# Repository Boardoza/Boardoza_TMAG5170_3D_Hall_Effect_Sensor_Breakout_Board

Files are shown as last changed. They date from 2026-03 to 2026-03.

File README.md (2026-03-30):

# Boardoza TMAG5170 3D Hall-Effect Sensor Breakout Board

The **Boardoza TMAG5170** is a high-precision **3D linear hall-effect sensor breakout board** based on the **Texas Instruments TMAG5170**. This device integrates **three independent Hall sensors (X, Y, and Z axes)** along with a precision signal chain and a 12-bit ADC, enabling accurate magnetic field measurement in compact and high-performance systems.

With support for high-speed **SPI communication (up to 10 MHz)** and sampling rates up to **20 ksps**, the TMAG5170 is ideal for real-time direction sensing applications. Integrated diagnostics, angle calculation (CORDIC engine), and an on-chip temperature sensor provide enhanced reliability and system-level drift compensation. This breakout board is perfect for **industrial automation, robotics, motor control, contactless direction sensing, and smart mechatronic systems.**

## [Click here to purchase!](https://www.ozdisan.com/ureticiler/boardoza)

| Front Side | Back Side |
|:---:|:---:|
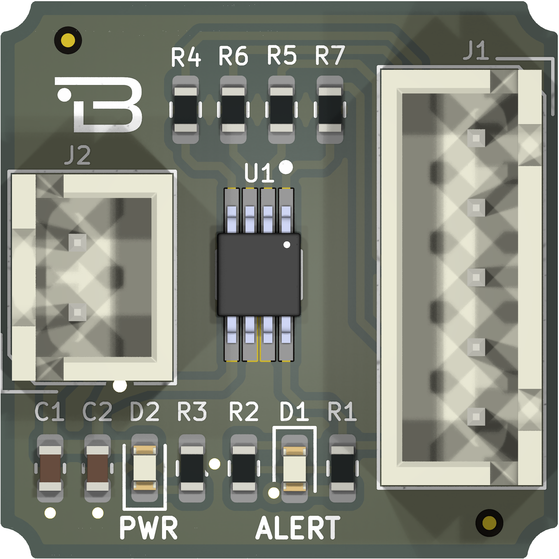
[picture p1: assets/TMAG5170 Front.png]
TMAG5170 Front
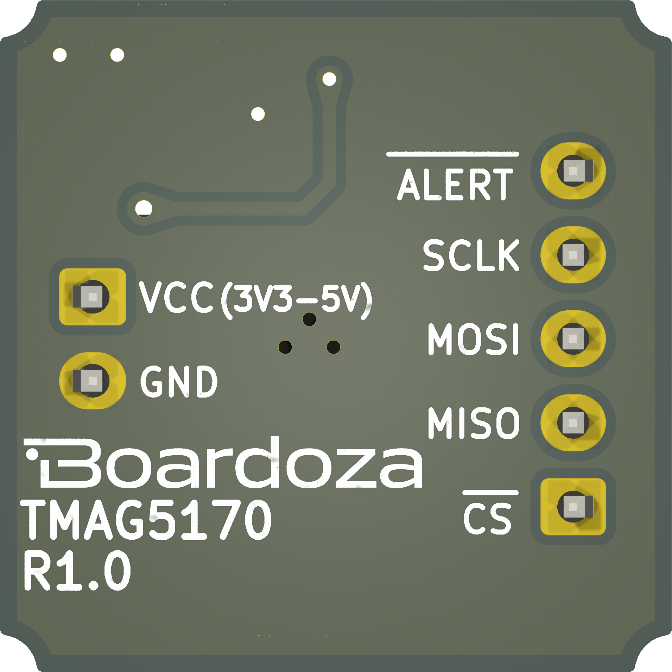
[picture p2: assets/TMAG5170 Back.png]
TMAG5170 Back
|  |  |

---

## Key Features

- **High-Precision 3D Magnetic Sensing:** Measures magnetic field on independent X, Y, and Z axes for accurate direction detection.
- **High-Speed SPI Interface:** Supports up to 10 MHz SPI with integrated CRC for secure communication.
- **Integrated Temperature Sensor:** < ±2°C error for system-level thermal compensation.
- **Ultra-Low Power Operation:** 5 nA deep sleep mode and 1.5 µA autonomous wake-up mode.
- **Smart ALERT Pin:** Can trigger conversions or indicate conversion completion.
- **Built-in Diagnostics:** Integrated fault detection and system monitoring features.
- **On-Chip CORDIC Engine:** Provides direct angle calculation with gain and offset correction.

---

## Technical Specifications

**Model:** TMAG5170A1  
**Manufacturer:** Boardoza   
**Manufacturer IC:** Texas Instruments  
**Functions:** 3D Hall-Effect Sensor   
**Input Voltage:** 2.3V – 5.5V DC  
**Interface:** SPI (up to 10 MHz, CRC supported)  
**Magnetic Field Ranges:** ±25 mT / ±50 mT / ±100 mT (selectable)  
**ADC Resolution:** 12-bit  
**Maximum Sampling Rate:** 20 ksps (single axis)  
**Linear Measurement Error:** ±2.6% (max at 25°C)  
**Sensitivity Temperature Drift:** ±2.8% (max)  
**Temperature Sensor Accuracy:** ±2°C (typical)  
**Deep Sleep Current:** 5 nA (typical)  
**Sleep Mode Current:** 1.5 µA (typical)  
**Active Mode Current:** 3.4 mA (typical)  
**Operating Temperature Range:** –40°C to +150°C  
**Board Dimensions:** 20 mm x 20 mm  

---

## Board Pinout

### ( J1 ) SPI Connector

| Pin Number | Pin Name | Description |
|:---:|:---:|---|
| 1 | nCS | Chip Select (Active Low) |
| 2 | MISO | SPI Data Output |
| 3 | MOSI | SPI Data Input |
| 4 | SCLK | SPI Clock |
| 5 | nALERT | Conversion Status / Trigger Output (Active Low) |

### ( J2 ) Power Connector

| Pin Number | Pin Name | Description |
|:---:|:---:|---|
| 1 | VCC | 2.3V – 5.5V Power Supply Input |
| 2 | GND | Ground Reference |

---

## Board Dimensions

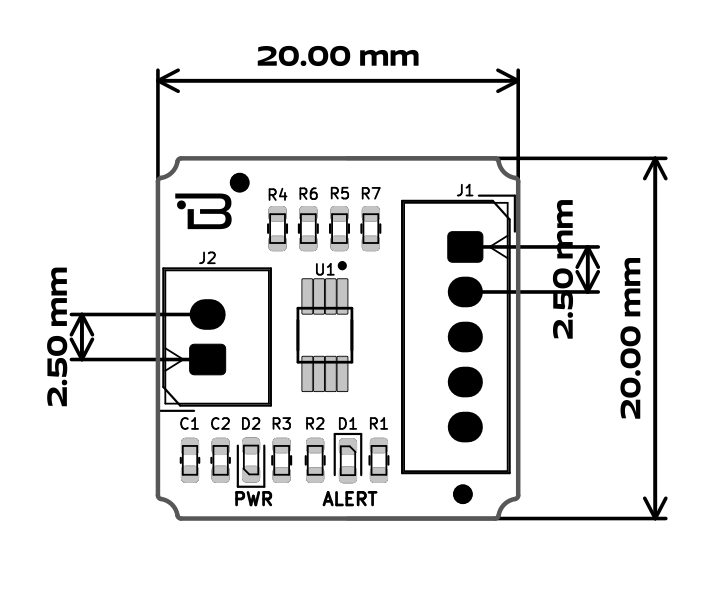
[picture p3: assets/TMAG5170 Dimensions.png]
TMAG5170 Dimension


---

## Step Files

[Boardoza TMAG5170.step](./assets/TMAG5170%20Step.step)

---

## Datasheet

[TMAG5170 Datasheet.pdf](./assets/TMAG5170%20Datasheet.pdf)

---

## Version History

- V1.0.0 - Initial Release

---

## Support

- If you have any questions or need support, please contact **support@boardoza.com**

---

## **License**

This repository contains both hardware and software components:

### **Hardware Design**

[][cc-by-sa]

All hardware design files are licensed under [Creative Commons Attribution-ShareAlike 4.0 International License][cc-by-sa].

[cc-by-sa]: http://creativecommons.org/licenses/by-sa/4.0/
[cc-by-sa-shield]: https://img.shields.io/badge/License-CC%20BY--SA%204.0-lightgrey.svg

### **Software/Firmware**

[][bsd]

All software and firmware are licensed under [BSD 3-Clause License][bsd].

[bsd]: https://opensource.org/licenses/BSD-3-Clause
[bsd-shield]: https://img.shields.io/badge/License-BSD%203--Clause-blue.svg

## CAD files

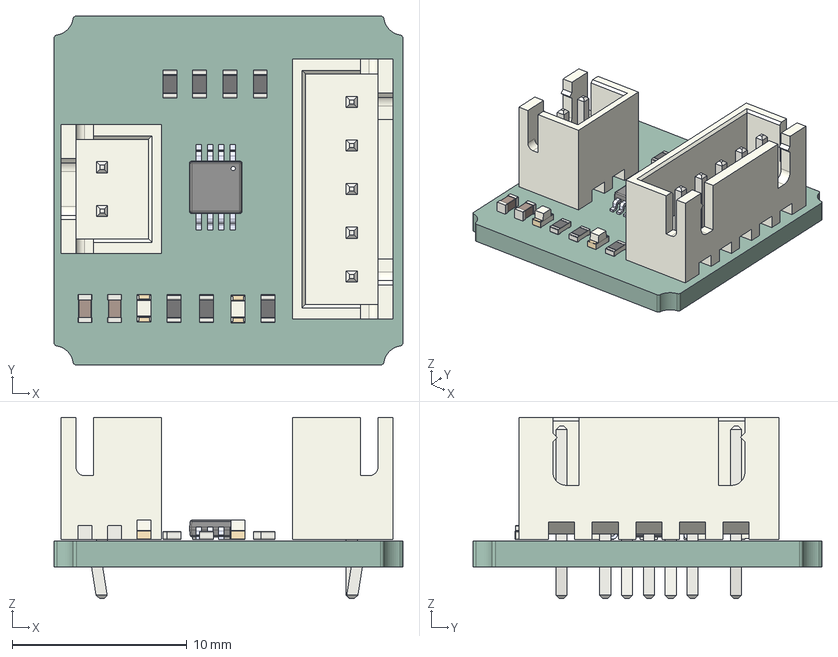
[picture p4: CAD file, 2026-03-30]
assets/TMAG5170 Step.step
20.0 x 20.0 x 10.4 mm
LED_0603_1608Metric x 2
TMAG5170A1QDGKR
C_0603_1608Metric x 2
R_0603_1608Metric x 7
JST_XH_B5B-XH-A_1x05_P2.50mm_Vertical
JST_XH_B2B-XH-A_1x02_P2.50mm_Vertical
B-TMAG5170-BRK_PCB

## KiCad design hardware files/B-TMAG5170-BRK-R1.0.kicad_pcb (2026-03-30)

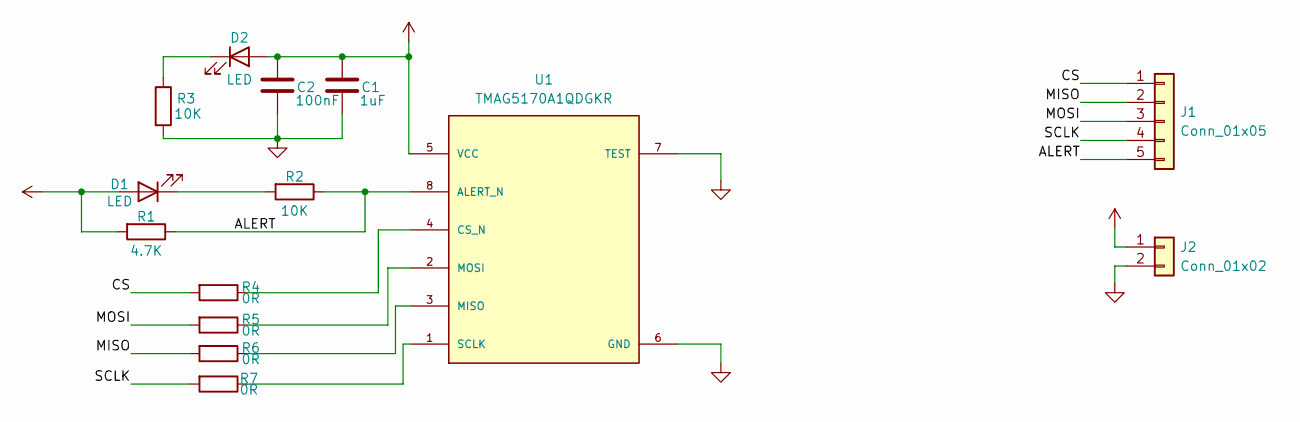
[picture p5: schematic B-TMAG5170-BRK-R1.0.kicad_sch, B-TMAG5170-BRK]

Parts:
C1: 1uF; C_0603_1608Metric; MPN CL10A105KO8NNNC
C2: 100nF; C_0603_1608Metric; MPN MCF03KTB500104
D1, D2: LED; LED_0603_1608Metric; MPN LTST-C190KRKT
J1: Conn_01x05; 2317-05S_1x05_P2.50mm_Vertical; MPN 2317-05S
J2: Conn_01x02; 2317-02S_1x02_P2.50mm_Vertical; MPN 2317-02S
R1: 4.7K; R_0603_1608Metric; MPN CRT03F7E4701
R2, R3: 10K; R_0603_1608Metric; MPN CRT03F7E1002
R4, R5, R6, R7: 0R; R_0603_1608Metric; MPN CRT03J7-R0R0
U1: TMAG5170A1QDGKR; DGK0008A-IPC_A; MANUFACTURER_PART_NUMBER TMAG5170A1QDGKR

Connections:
/ALERT: J1.5, R1.1, R2.1, U1.8 (ALERT_N)
/CS: J1.1, R4.2
/MISO: J1.2, R6.2
/MOSI: J1.3, R5.2
/SCLK: J1.4, R7.2
GND: C1.1, C2.1, J2.2, R3.2, U1.6 (GND), U1.7 (TEST)
unnamed: D1.1 (K), R2.2
unnamed: D2.1 (K), R3.1
unnamed: R4.1, U1.4 (CS_N)
unnamed: R6.1, U1.3 (MISO)
unnamed: R5.1, U1.2 (MOSI)
unnamed: R7.1, U1.1 (SCLK)
VCC: C1.2, C2.2, D1.2 (A), D2.2 (A), J2.1, R1.2, U1.5 (VCC)

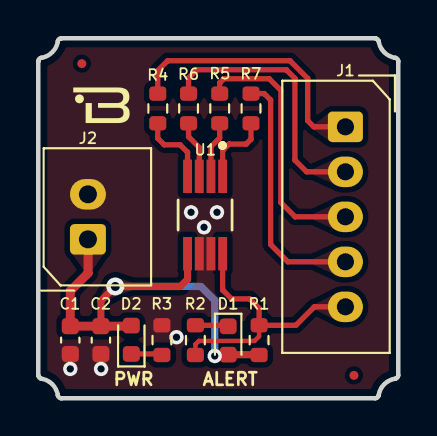
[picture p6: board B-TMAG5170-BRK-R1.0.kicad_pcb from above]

Board: 2 copper layers, 20.0 x 20.0 mm, 14 parts (0 on the bottom side), 13 nets.

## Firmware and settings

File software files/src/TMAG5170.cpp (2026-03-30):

#include "TMAG5170.h"

/**
 * @brief Constructor for the TMAG5170 class.
 * 
 * Initializes the TMAG5170 object by setting the chip select pin and SPI settings.
 * 
 * @param csPin The chip select pin number for the TMAG5170 sensor.
 */
TMAG5170::TMAG5170(uint8_t csPin)
  : _cs(csPin)
  , _settings(10000000, MSBFIRST, SPI_MODE0)
{}

/**
 * @brief Initializes the TMAG5170 sensor.
 * 
 * This function configures the TMAG5170 sensor by setting up the SPI interface and
 * initializing the sensor in active measurement mode.
 */
void TMAG5170::begin() {
  pinMode(_cs, OUTPUT);
  csHigh();
  SPI.begin();               // VSPI: SCK=18, MISO=19, MOSI=23
}

/**
 * @brief Sets the chip select pin to LOW.
 */
void TMAG5170::csLow()  { digitalWrite(_cs, LOW);  }

/**
 * @brief Sets the chip select pin to HIGH.
 */
void TMAG5170::csHigh() { digitalWrite(_cs, HIGH); }

/**
 * @brief Configures a register in the TMAG5170 sensor.
 * 
 * This function sends a configuration command to the TMAG5170 sensor over SPI
 * and waits for the response. It handles the CRC calculation and ensures proper
 * communication with the sensor.
 * 
 * @param rw The read/write flag (READ_FLAG or WRITE_FLAG).
 * @param reg The register address to be configured.
 * @param data The data to be written to the register.
 */
void TMAG5170::regConfig(uint8_t rw, uint8_t reg, uint16_t data) {
  // rw flag + register
  uint8_t tx[4] = {
    uint8_t(rw | reg),        // byte0: RW|ADDR
    uint8_t(data >> 8),       // byte1: DATA[15:8]
    uint8_t(data & 0xFF),     // byte2: DATA[7:0]
    0x00                      // byte3: placeholder for CRC
  };

  // Collect the 28-bit part in a uint32:
  uint32_t frame28 = (uint32_t(tx[0]) << 20)
                   | (uint32_t(tx[1]) << 12)
                   | (uint32_t(tx[2]) << 4);

  // Calculate CRC4
  tx[3] = calculateCRC4(frame28);

  // send / receive
  uint8_t rx[4];
  SPI.beginTransaction(_settings);
    csLow();
      for (int i = 0; i < 4; ++i) rx[i] = SPI.transfer(tx[i]);
    csHigh();
  SPI.endTransaction();
}

/**
 * @brief Reads data from a register in the TMAG5170 sensor.
 * 
 * This function sends a read command to the TMAG5170 sensor over SPI and
 * returns the 16-bit data value read from the specified register.
 * 
 * @param reg The register address to read from.
 * @return The 16-bit data value read from the register.
 */
uint16_t TMAG5170::readRegData(uint8_t reg) {
  uint8_t tx[4] = { uint8_t(READ_FLAG | reg), 0x00, 0x00, 0x00 };
  uint8_t rx[4];

  SPI.beginTransaction(_settings);
  csLow();
  for(int i=0; i<4; i++) rx[i] = SPI.transfer(tx[i]);
  csHigh();
  SPI.endTransaction();

  return (uint16_t(rx[1]) << 8) | rx[2];
}

/**
 * @brief Initializes the TMAG5170 sensor for evaluation mode.
 * 
 * This function configures the TMAG5170 sensor in evaluation mode by setting
 * up the necessary registers and waiting for the sensor to initialize.
 */
void TMAG5170::initForEval() {
  regConfig(WRITE_FLAG, TEST_CONFIG, CRC_DIS_CRCdisabled);
  delay(5);
  // 1) Device configuration
  regConfig(WRITE_FLAG, DEVICE_CONFIG, DeviceStart);
  delay(5);
  // 2) Sensor configuration
  regConfig(WRITE_FLAG, SENSOR_CONFIG,
            ANGLE_EN_XY      |
            SLEEPTIME_1ms    |
            MAG_CH_EN_XYZZYX |
            Z_RANGE_25mT     |
            Y_RANGE_25mT     |
            X_RANGE_25mT);
  delay(5);
  // 3) System configuration
  regConfig(WRITE_FLAG, SYSTEM_CONFIG,
            DIAG_SEL_AllDataPath    |
            TRIGGER_MODE_SPI        |
            DATA_TYPE_32bit         |
            DIAG_EN_AFEdiagnosticsDisabled |
            Z_HLT_EN_ZaxisLimitCheckoff    |
            Y_HLT_EN_YaxisLimitCheckoff    |
            X_HLT_EN_XaxisLimitCheckoff);
    //regConfig(WRITE_FLAG, SYSTEM_CONFIG, 0x02C7);
  delay(5);
  // 4) Test configuration

  // 5) Mag gain configuration
  regConfig(WRITE_FLAG, MAG_GAIN_CONFIG, GAIN_SEL_noAxisSelected);
  delay(5);
  // 6) Finally, DeviceStart is set again to proceed with measurements
  regConfig(WRITE_FLAG, DEVICE_CONFIG, DeviceStart);
  delay(5);
}

/**
 * @brief Reads the X-axis magnetic field value from the TMAG5170 sensor.
 * 
 * This function reads the raw X-axis magnetic field value from the sensor
 * and converts it to milliTesla (mT) using a linear conversion factor.
 * 
 * @return The X-axis magnetic field value in mT.
 */
float TMAG5170::getX() {
  int16_t raw = int16_t(readRegData(X_CH_RESULT));
  return raw * 50.0f  / 32768.0f;
}

/**
 * @brief Reads the Y-axis magnetic field value from the TMAG5170 sensor.
 * 
 * This function reads the raw Y-axis magnetic field value from the sensor
 * and converts it to milliTesla (mT) using a linear conversion factor.
 * 
 * @return The Y-axis magnetic field value in mT.
 */
float TMAG5170::getY() {
  int16_t raw = int16_t(readRegData(Y_CH_RESULT));
  return raw * 25.0f  / 32768.0f;
}

/**
 * @brief Reads the Z-axis magnetic field value from the TMAG5170 sensor.
 * 
 * This function reads the raw Z-axis magnetic field value from the sensor
 * and converts it to milliTesla (mT) using a linear conversion factor.
 * 
 * @return The Z-axis magnetic field value in mT.
 */
float TMAG5170::getZ() {
  int16_t raw = int16_t(readRegData(Z_CH_RESULT));
  return raw * 25.0f  / 32768.0f;
}

/**
 * @brief Reads the temperature value from the TMAG5170 sensor.
 * 
 * This function reads the raw temperature value from the sensor and converts
 * it to degrees Celsius using a linear conversion factor.
 * 
 * @return The temperature value in degrees Celsius.
 */
float TMAG5170::getTemperature() {
  uint16_t t = readRegData(TEMP_RESULT);
  return ECHAR_T_SENS_T0 + ( (float(t) - ECHAR_T_ADC_T0) / ECHAR_T_ADC_RES );
}

/**
 * @brief Reads the angle value from the TMAG5170 sensor.
 * 
 * This function reads the raw angle value from the sensor and converts it to
 * degrees using a linear conversion factor.
 * 
 * @return The angle value in degrees.
 */
float TMAG5170::getAngle() {
  uint16_t a = readRegData(ANGLE_RESULT);
  // upper 12 bits are degrees, lower 4 bits are fraction
  return float(a >> 4); //+ float(a & 0x0F) / 16.0f;
}
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

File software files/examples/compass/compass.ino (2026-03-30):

#include <TMAG5170.h>

TMAG5170 mag(5);   // CS = GPIO5 (VSPI SS)

void setup() {
  Serial.begin(115200);
  mag.begin();
  mag.initForEval();
  delay(1000);
}

void loop() {
  Serial.print("X(mT): ");   Serial.println(mag.getX(),  3);
  Serial.print("Y(mT): ");   Serial.println(mag.getY(),  3);
  Serial.print("Z(mT): ");   Serial.println(mag.getZ(),  3);
  Serial.print("Temp(C): "); Serial.println(mag.getTemperature(), 2);
  Serial.print("Angle: ");   Serial.println(mag.getAngle(), 2);
  Serial.println();

  delay(500);
}

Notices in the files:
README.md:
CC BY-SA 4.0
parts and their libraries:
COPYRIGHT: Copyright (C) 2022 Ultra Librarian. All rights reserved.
